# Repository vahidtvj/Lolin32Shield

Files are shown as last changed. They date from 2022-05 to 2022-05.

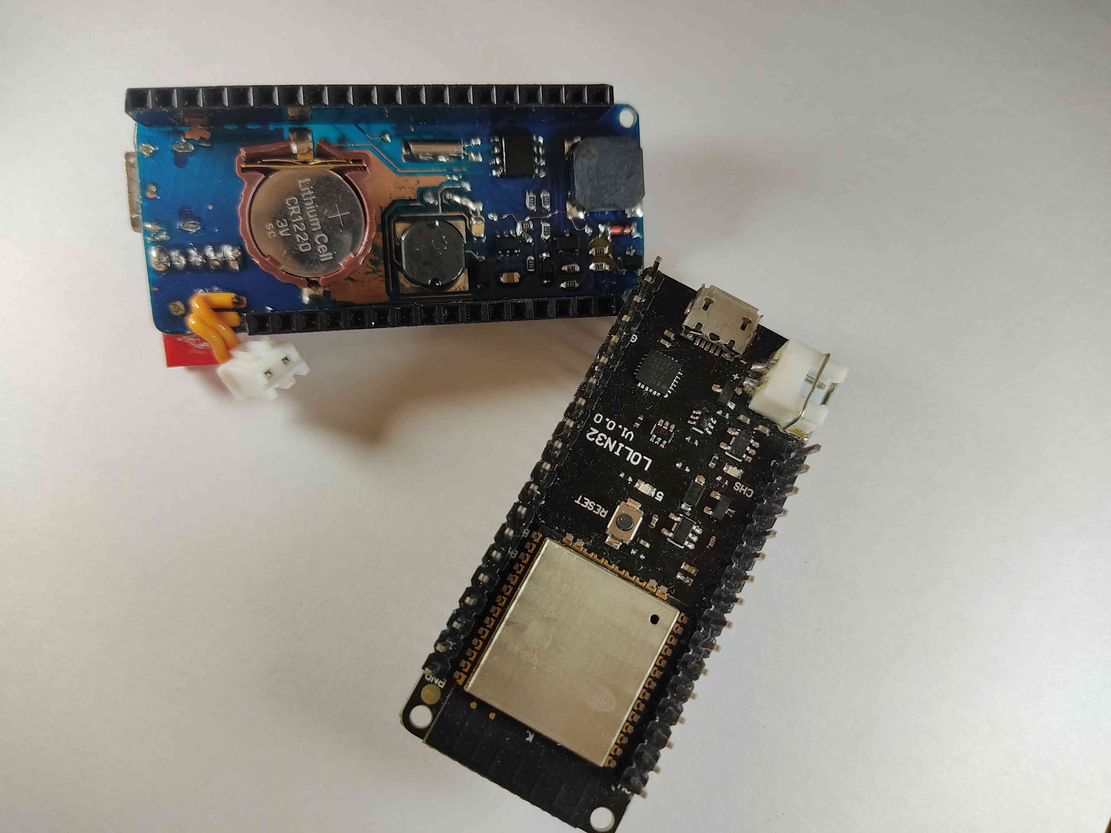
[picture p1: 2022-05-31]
pics/IMG_20220531_204243_2.jpg

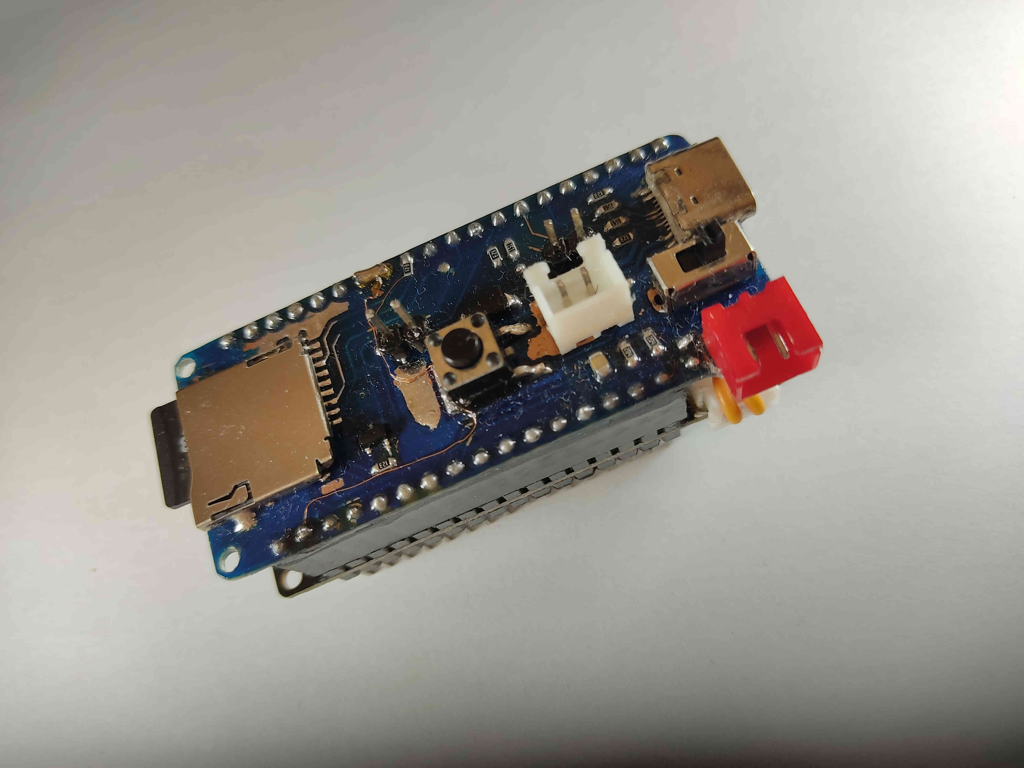
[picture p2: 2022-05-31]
pics/IMG_20220531_203105_2.jpg

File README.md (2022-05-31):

# Lolin 32 Shield

A collection of useful stuff to have on a ESP32 dev board

## Whats on the board?

- A Micro SD card
- **DS1307**, `for time keeping`
- Battery Switch
- Battery Probe `(This is Builtin on Lolin d32 board)`
- Passive Buzzer, `when you want to annoy others!`
- QC3 capable USB port, `so you can have 12v`
- PWM controlled header, `in case you want to control sth high power (usable with QC)`
- A voltage booster, `cuz some modules just don't work with 3.3v`
- And Mosfets, `To shut everthing off`

Schematic
Schematic

## GPIO Wiring

| PIN | GPIO |
| :---: | :--: |
| SD_CS |  5 |
| <span style="text-decoration:overline">SD_EN</span> |  33  |
| BUZZER |  32  |
| VBAT |  35  |
| BOOST_EN |  27  |
| USB_DM |  17  |
| USB_DP |  16  |
| MOSFET |  4 |

### Some Notes

Due to availability, I had to use _DS1307_ RTC chip. **PCF8523T** is a much better alternative. DS1307 requires 5v to operate, so when powering from a lipo battery you have to enable the voltage booster.

SD card can be disabled using **SD_EN** PIN to save power. Don't forget to set it low before trying to read the card.

The USB_C port is there so you can connect a second power source (**Not connected to ESP**). This is useful when you have devices that draw more current and your laptop's usb ports can't supply enough power.
Also Quick Charge Enabled Adapters can be used to get higher voltages like 12v ( `voltage level is controlled by the ESP, checkout `[QC3Control](https://github.com/vahidtvj/QC3Control) ).

### Future Changes

- **PCF8523T** as a drop-in replacement for _DS1307_
- 3.3v Regulator for USB_C input (has to work with QC3 voltage levels)
- A RESET Button

## License

This project is licensed under the [MIT License](LICENSE)

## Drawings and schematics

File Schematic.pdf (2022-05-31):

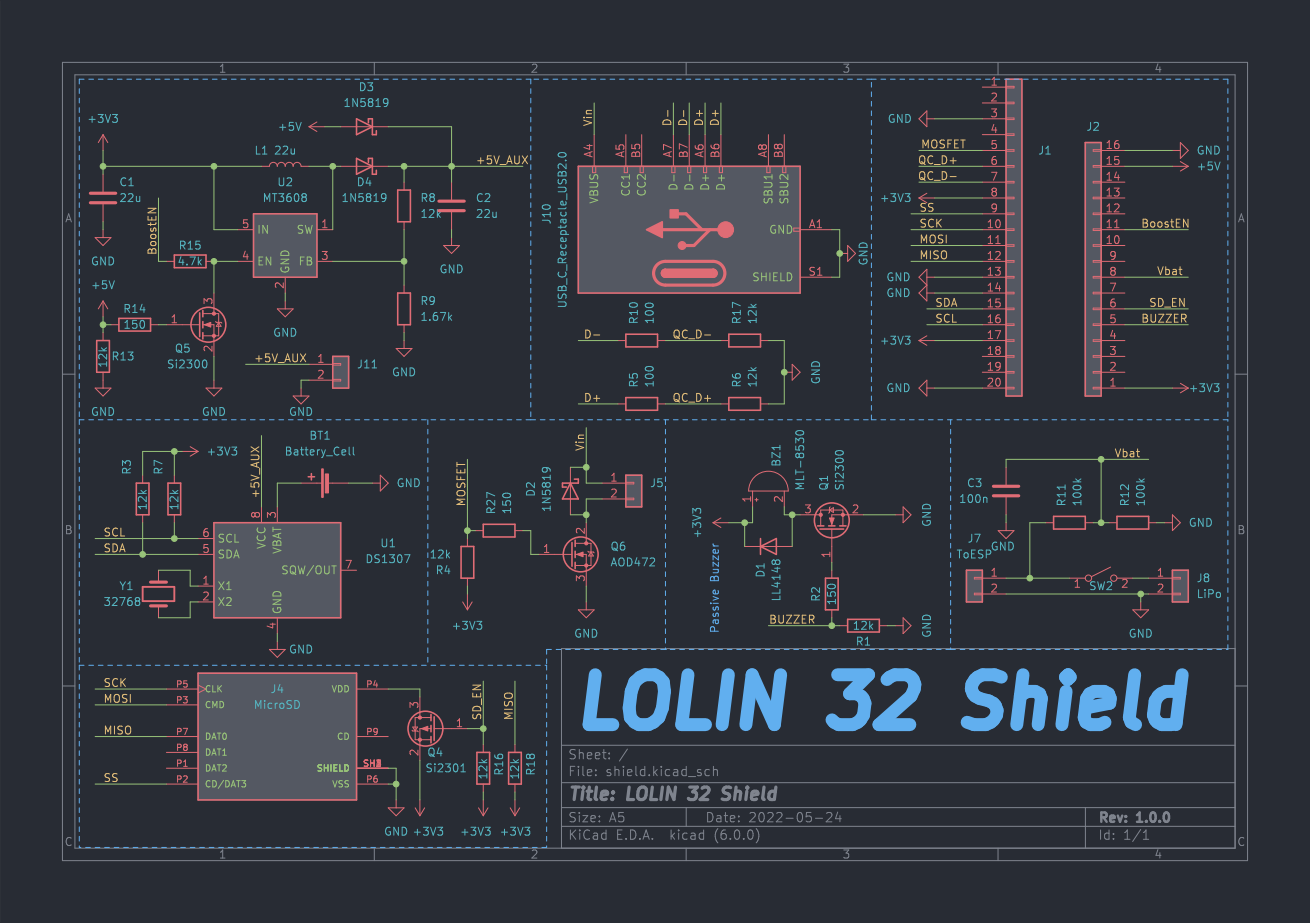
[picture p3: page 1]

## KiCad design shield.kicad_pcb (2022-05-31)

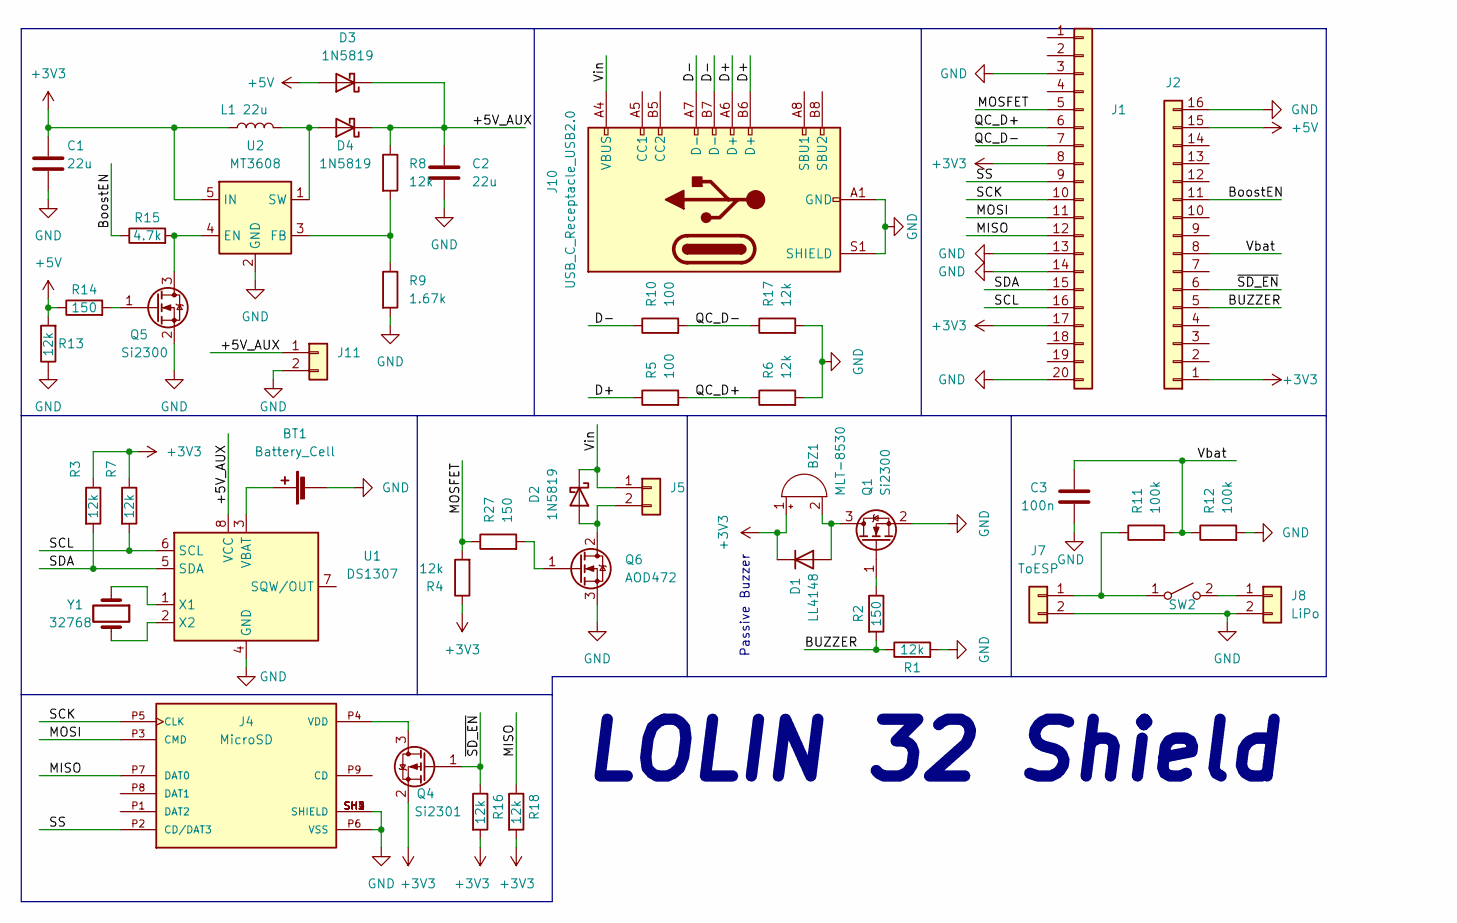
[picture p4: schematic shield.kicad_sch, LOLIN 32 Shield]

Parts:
BT1: Battery_Cell; CR1220Holder_SMD
BZ1: MLT-8530; MagneticBuzzer_Kobitone_254-EMB84Q-RO
C1, C2: 22u; C_0805_2012Metric_Pad1.18x1.45mm_HandSolder
C3: 100n; C_0805_2012Metric_Pad1.18x1.45mm_HandSolder
D1: LL4148; D_MiniMELF
D2: 1N5819; D_SMA
D3, D4: 1N5819; Nexperia_CFP3_SOD-123W
J1: Conn_01x20; PinSocket_1x20_P2.54mm_Vertical
J2: Conn_01x16; PinSocket_1x16_P2.54mm_Vertical
J4: MicroSD; GCT_MEM2075-00-140-01-A; PARTREV A
J5: Conn_01x02; JST_XH_B2B-XH-A_1x02_P2.50mm_Vertical
J7: ToESP; PinHeader_1x02_P2.00mm_Vertical
J8: LiPo; JST_XH_S2B-XH-A_1x02_P2.50mm_Horizontal
J10: USB_C_Receptacle_USB2.0; USB_C_Receptacle_HRO_TYPE-C-31-M-12
J11: Conn_01x02; PinHeader_1x02_P2.54mm_Vertical
L1: 22u; L_Bourns-SRN8040_8x8.15mm
Q1, Q5: Si2300; SOT-23
Q4: Si2301; SOT-23
Q6: AOD472; TO-252-2
R1, R3, R4, R6, R7, R8, R13, R16, R17, R18: 12k; R_0603_1608Metric_Pad0.98x0.95mm_HandSolder
R2, R14, R27: 150; R_0603_1608Metric_Pad0.98x0.95mm_HandSolder
R5, R10: 100; R_0603_1608Metric_Pad0.98x0.95mm_HandSolder
R9: 1.67k; R_0603_1608Metric_Pad0.98x0.95mm_HandSolder
R11, R12: 100k; R_0805_2012Metric_Pad1.20x1.40mm_HandSolder
R15: 4.7k; R_0603_1608Metric_Pad0.98x0.95mm_HandSolder
SW2: SW_SPST; SW_Slide_1P2T_CK_OS102011MS2Q
U1: DS1307; SOIC-8_3.9x4.9mm_P1.27mm
U2: MT3608; SOT-23-6
Y1: 32768; Crystal_DS26_D2.0mm_L6.0mm_Horizontal_1EP_style1

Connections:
+3V3: BZ1.1 (-), C1.1, D1.1 (K), J1.8, J1.17, J2.1, L1.1, Q4.2 (S), R3.1, R4.1, R7.1, R16.2, R18.2, U2.5 (IN)
+5V: D3.2 (A), J2.15, R13.2, R14.1
/+5V_AUX: C2.1, D3.1 (K), D4.1 (K), J11.1, R8.1, U1.8 (VCC)
/BUZZER: J2.5, R1.1, R2.2
/BoostEN: J2.11, R15.1
/D+: J10.A6 (D+), J10.B6 (D+), R5.1
/D-: J10.A7 (D-), J10.B7 (D-), R10.1
/MISO: J1.12, J4.P7 (DAT0), R18.1
/MOSFET: J1.5, R4.2, R27.1
/MOSI: J1.11, J4.P3 (CMD)
/QC_D+: J1.6, R5.2, R6.1
/QC_D-: J1.7, R10.2, R17.1
/SCK: J1.10, J4.P5 (CLK)
/SCL: J1.16, R7.2, U1.6 (SCL)
/SDA: J1.15, R3.2, U1.5 (SDA)
/SD_EN: J2.6, Q4.1 (G), R16.1
/SS: J1.9, J4.P2 (CD/DAT3)
/Vbat: C3.2, J2.8, R11.2, R12.1
/Vin: D2.1 (K), J5.1, J10.A4 (VBUS), J10.A9 (VBUS), J10.B4 (VBUS), J10.B9 (VBUS); also elsewhere on the board
GND: BT1.2 (-), C1.2, C2.2, C3.1, J1.3, J1.13, J1.14, J1.20, J2.16, J4.P6 (VSS), J4.SH1 (SHIELD), J4.SH2 (SHIELD), J4.SH3 (SHIELD), J4.SH4 (SHIELD), J7.2, J8.2, J10.A1 (GND), J10.A12 (GND), J10.B1 (GND), J10.B12 (GND), J10.S1 (SHIELD), J11.2, Q1.2 (S), Q5.2 (S), Q6.3 (S), R1.2, R6.2, R9.2, R12.2, R13.1, R17.2, U1.4 (GND), U2.2 (GND); also elsewhere on the board
unnamed: BT1.1 (+), U1.3 (VBAT)
unnamed: BZ1.2 (+), D1.2 (A), Q1.3 (D)
unnamed: D2.2 (A), J5.2, Q6.2 (D)
unnamed: D4.2 (A), L1.2, U2.1 (SW)
unnamed: J4.P4 (VDD), Q4.3 (D)
unnamed: J7.1, R11.1, SW2.1 (A)
unnamed: J8.1, SW2.2 (B)
unnamed: Q1.1 (G), R2.1
unnamed: Q5.1 (G), R14.2
unnamed: Q5.3 (D), R15.2, U2.4 (EN)
unnamed: Q6.1 (G), R27.2
unnamed: R8.2, R9.1, U2.3 (FB)
unnamed: U1.1 (X1), Y1.1
unnamed: U1.2 (X2), Y1.2

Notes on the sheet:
Passive Buzzer
LOLIN 32 Shield

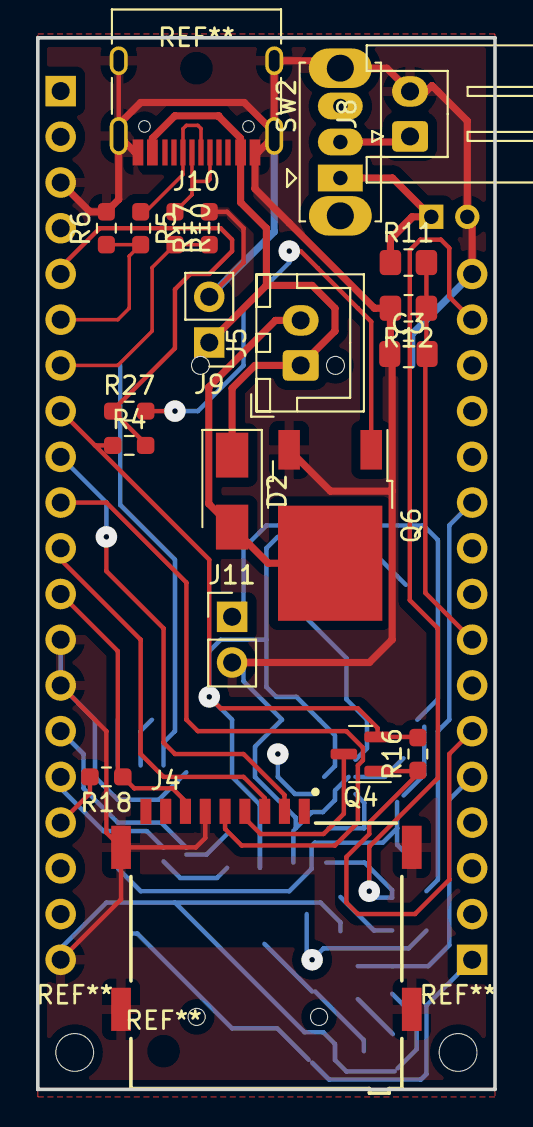
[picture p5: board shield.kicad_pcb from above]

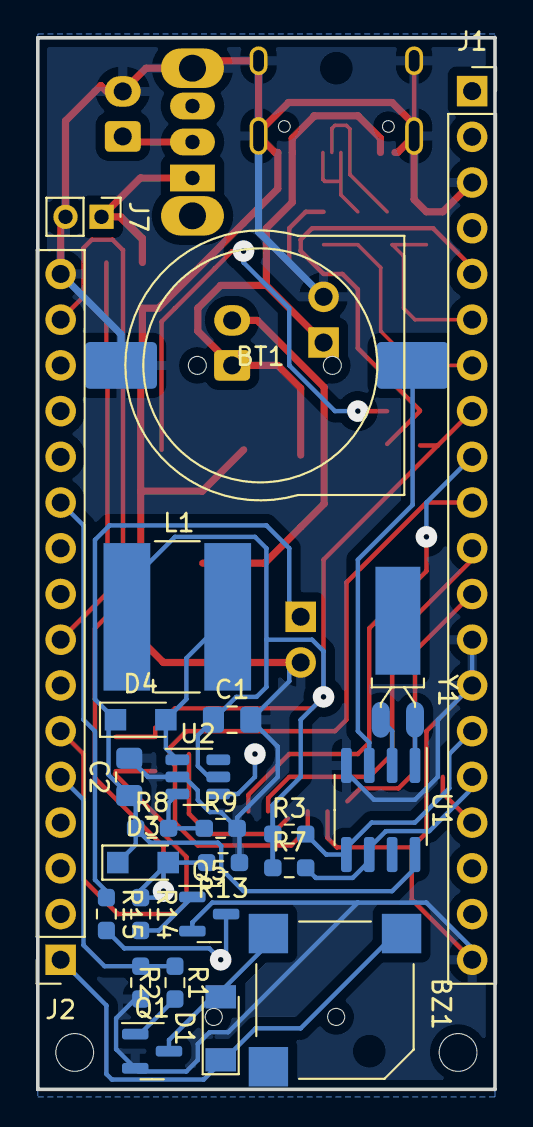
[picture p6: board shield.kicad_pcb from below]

Board: 4 copper layers, 25.4 x 58.4 mm, 46 parts (25 on the bottom side), 34 nets.

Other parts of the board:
J9: Conn_01x02; PinHeader_1x02_P2.54mm_Vertical

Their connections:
/Vin: J9.1; also elsewhere on the board
GND: J9.2; also elsewhere on the board
